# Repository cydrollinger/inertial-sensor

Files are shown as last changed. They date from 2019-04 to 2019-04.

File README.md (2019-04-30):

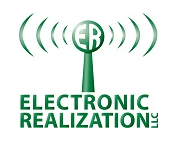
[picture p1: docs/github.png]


>Electronic Realization L.L.C.								   
>Design: 9 axis inertial sensor with bluetooth communication		   
>Engineer: Cy Drollinger								   
>Date: 2/19												           
>Email: cy@elec-real.com
>Website: https://elec-real.com								   
>Address: 2023 Stadium Dr Suite 2B #210 Bozeman, MT 59715				   
>Phone: 406-539-8117	

**NOTE:**
 This design has been tested and functions as specified. The design is provided gratis, so, please 
 think critically while utilizing and or redesigning. Open electronic circuitry can be dangerous due 
 to easily shorting circuits which can generate immediate and intense heat resulting in fire. Conversation is
 welcome to improve this design and repository, but, be advised ER is a professional design house and
 monetary compensation is required for additional work toward this design enabling your success.			   
	 
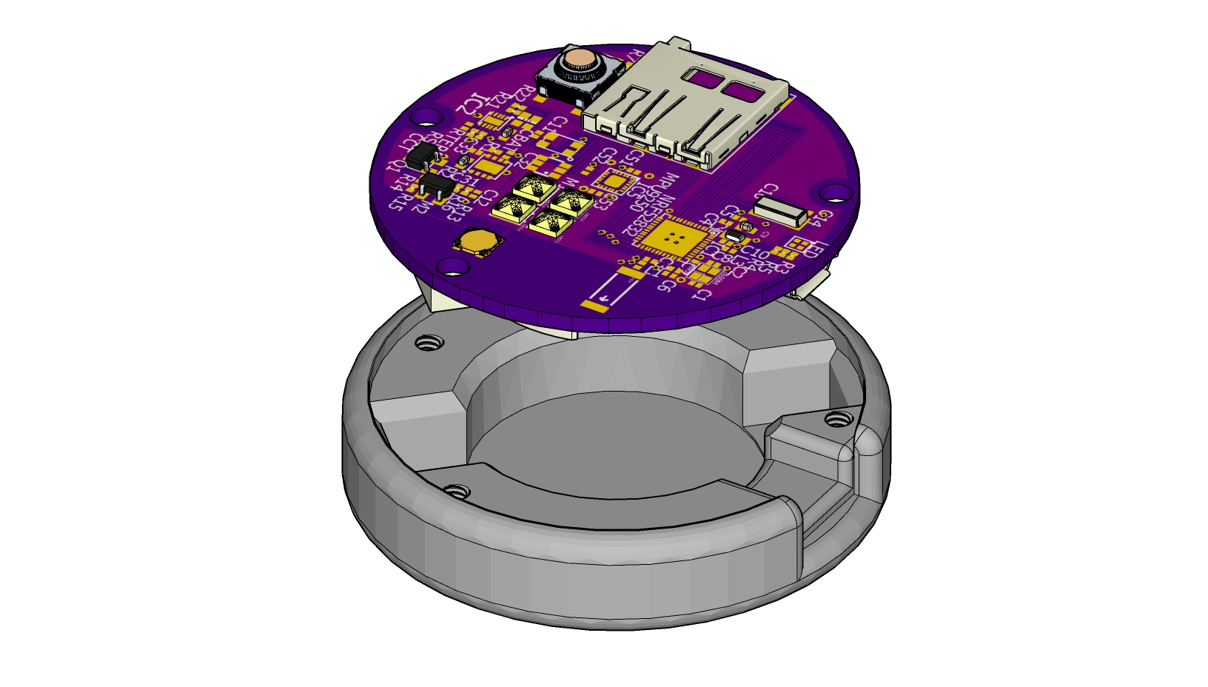
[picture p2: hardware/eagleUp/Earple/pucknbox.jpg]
Inertial Sensor


**PURPOSE:**
This electronic system is capable of sampling inertial data from the mpu9250 at 1 kHz and storing to 
a uSD card for GB storage, fatfs. The design files were created with Eagle Cadsoft v7.7 as a 
two layer board. Free Eagle version would be capable of viewing, and editing these files for redesign. 

>**File Arcitecture with a terse description**

* FOLDERS:
	* docs		: datasheets charging IC and battery holder
	* hardware	: eagle cadsoft(v7.7) hardware design files 	
		* eagleup		: 3D files 
		* library		: eagle part files 
		* manufacturing	: files required to produce the design
			* bom	: files created to order the parts
					* batteryCharger.txt	: 
					* batteryv1.1.csv	: digikey order
					* hundredUnits.txt	
			* gerber	: files generated to manufacture the board
			* 
	* firmware
	* software

	* readme.md	: this file

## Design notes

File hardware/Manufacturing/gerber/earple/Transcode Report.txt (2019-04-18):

   ---- Transcoding 'C:\Users\Cy\Documents\eagle\gerber\ERpuck\earple\toppaste.gtp' ----   Mon Feb 18 14:16:38 2019

D10   --> D100
D11   --> D101
D12   --> D102
D13   --> D103
D14   --> D104
D15   --> D105
D16   --> D106
D17   --> D107
D18   --> D108
D19   --> D109
D20   --> D110
-----------------------------------------------------------------

   ---- Transcoding 'C:\Users\Cy\Documents\eagle\gerber\ERpuck\earple\topstop.GTS' ----   Mon Feb 18 14:16:38 2019

D10   --> D111
D11   --> D112
D12   --> D113
D13   --> D114
D14   --> D115
D15   --> D116
D16   --> D117
D17   --> D118
D18   --> D119
D19   --> D120
D20   --> D121
D21   --> D122
D22   --> D123
D23   --> D124
D24   --> D125
D25   --> D126
D26   --> D127
D27   --> D128
D28   --> D129
D29   --> D130
D30   --> D131
D31   --> D132
D32   --> D133
D33   --> D134
D34   --> D135
D35   --> D136
D36   --> D137
-----------------------------------------------------------------

   ---- Transcoding 'C:\Users\Cy\Documents\eagle\gerber\ERpuck\earple\top.GTL' ----   Mon Feb 18 14:16:38 2019

D10   --> D138
D11   --> D139
D12   --> D140
D13   --> D141
D14   --> D142
D15   --> D143
D16   --> D144
D17   --> D145
D18   --> D146
D19   --> D147
D20   --> D148
D37   --> D149
D38   --> D150
D39   --> D151
D40   --> D152
D41   --> D153
D42   --> D154
D43   --> D155
D44   --> D156
D45   --> D157
D46   --> D158
-----------------------------------------------------------------

   ---- Transcoding 'C:\Users\Cy\Documents\eagle\gerber\ERpuck\earple\bottom.GBL' ----   Mon Feb 18 14:16:39 2019

D10   --> D159
D11   --> D160
D12   --> D161
D15   --> D162
D16   --> D163
D17   --> D164
D18   --> D165
D19   --> D166
D20   --> D167
D21   --> D168
D22   --> D169
D23   --> D170
-----------------------------------------------------------------

   ---- Transcoding 'C:\Users\Cy\Documents\eagle\gerber\ERpuck\earple\botstop.GBS' ----   Mon Feb 18 14:16:39 2019

D10   --> D171
D11   --> D172
D12   --> D173
D13   --> D174
D16   --> D175
D17   --> D176
D18   --> D177
D19   --> D178
D20   --> D179
D21   --> D180
D22   --> D181
D23   --> D182
D24   --> D183
D25   --> D184
D26   --> D185
D27   --> D186
D28   --> D187
-----------------------------------------------------------------

   ---- Transcoding 'C:\Users\Cy\Documents\eagle\gerber\ERpuck\earple\botpaste.gbp' ----   Mon Feb 18 14:16:39 2019

D10   --> D188
D11   --> D189
D12   --> D190
-----------------------------------------------------------------

   ---- Transcoding 'C:\Users\Cy\Documents\eagle\gerber\ERpuck\earple\botsilk.GBO' ----   Mon Feb 18 14:16:39 2019

D10   --> D191
D11   --> D192
D12   --> D193
-----------------------------------------------------------------

   ---- Transcoding 'C:\Users\Cy\Documents\eagle\gerber\ERpuck\earple\outline.GKO' ----   Mon Feb 18 14:16:39 2019

D10   --> D194
D11   --> D195
-----------------------------------------------------------------

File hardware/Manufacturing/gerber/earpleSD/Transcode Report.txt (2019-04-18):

   ---- Transcoding 'C:\Users\Cy\Documents\eagle\gerber\ERpuck\earpleSD\toppaste.gtp' ----   Mon Feb 18 14:17:45 2019

D10   --> D100
D11   --> D101
D12   --> D102
D13   --> D103
D14   --> D104
D15   --> D105
D16   --> D106
D17   --> D107
D18   --> D108
D19   --> D109
D20   --> D110
-----------------------------------------------------------------

   ---- Transcoding 'C:\Users\Cy\Documents\eagle\gerber\ERpuck\earpleSD\topstop.GTS' ----   Mon Feb 18 14:17:45 2019

D10   --> D111
D11   --> D112
D12   --> D113
D13   --> D114
D14   --> D115
D15   --> D116
D16   --> D117
D17   --> D118
D18   --> D119
D19   --> D120
D20   --> D121
D21   --> D122
D22   --> D123
D23   --> D124
D24   --> D125
D25   --> D126
D26   --> D127
D27   --> D128
D28   --> D129
D29   --> D130
D30   --> D131
D31   --> D132
D32   --> D133
D33   --> D134
D34   --> D135
D35   --> D136
D36   --> D137
D37   --> D138
D38   --> D139
D39   --> D140
-----------------------------------------------------------------

   ---- Transcoding 'C:\Users\Cy\Documents\eagle\gerber\ERpuck\earpleSD\top.GTL' ----   Mon Feb 18 14:17:45 2019

D10   --> D141
D11   --> D142
D12   --> D143
D13   --> D144
D14   --> D145
D15   --> D146
D16   --> D147
D17   --> D148
D18   --> D149
D19   --> D150
D20   --> D151
D40   --> D152
D42   --> D153
D44   --> D154
D45   --> D155
D46   --> D156
D48   --> D157
-----------------------------------------------------------------

   ---- Transcoding 'C:\Users\Cy\Documents\eagle\gerber\ERpuck\earpleSD\bottom.GBL' ----   Mon Feb 18 14:17:45 2019

D10   --> D158
D11   --> D159
D12   --> D160
D15   --> D161
D16   --> D162
D17   --> D163
D18   --> D164
D19   --> D165
D20   --> D166
D21   --> D167
-----------------------------------------------------------------

   ---- Transcoding 'C:\Users\Cy\Documents\eagle\gerber\ERpuck\earpleSD\botstop.GBS' ----   Mon Feb 18 14:17:45 2019

D10   --> D168
D11   --> D169
D12   --> D170
D13   --> D171
D16   --> D172
D17   --> D173
D18   --> D174
D19   --> D175
D20   --> D176
D21   --> D177
D22   --> D178
D23   --> D179
-----------------------------------------------------------------

   ---- Transcoding 'C:\Users\Cy\Documents\eagle\gerber\ERpuck\earpleSD\botpaste.gbp' ----   Mon Feb 18 14:17:45 2019

D10   --> D180
D11   --> D181
D12   --> D182
-----------------------------------------------------------------

   ---- Transcoding 'C:\Users\Cy\Documents\eagle\gerber\ERpuck\earpleSD\botsilk.GBO' ----   Mon Feb 18 14:17:45 2019

D10   --> D183
D11   --> D184
D12   --> D185
-----------------------------------------------------------------

   ---- Transcoding 'C:\Users\Cy\Documents\eagle\gerber\ERpuck\earpleSD\outline.GKO' ----   Mon Feb 18 14:17:45 2019

D10   --> D186
D11   --> D187
-----------------------------------------------------------------

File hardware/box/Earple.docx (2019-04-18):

Specifications:

EARPLE BOARD:

Diameter: 1.8”

Holes:

1. (0.543” , 1.637) drill 3/32” #43 #42 .089 or .0935
2. (1.69” , 0.684) drill 3/32” #43 #42 .089 or .0935
3. (0.9” , 0.088”) drill 3/32” #43 #42 .089 or .0935
4. Tap for 4-40 NF or NC

Battery: (0.9 “ , .09”) 45 deg. Offset drawing included

Micro USB: ~(0.9” , 1.68”) 0 deg. Offset drawing included

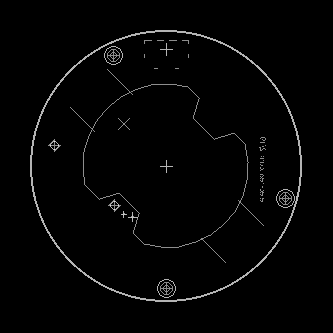
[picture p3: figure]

Electronic Realization llc 2023 Stadium Dr Ste. 2B #210 Bozeman, MT 59715 USA cell (406) 539-8117 E-mail cy@elec-real.com Web site www.elec-real.com

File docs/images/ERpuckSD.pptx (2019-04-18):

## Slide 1

12

Ay+

Gy+ ccw

9

Az+

Gz+ CCW

Ax+

3

Gx+ CCW

6

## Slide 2

Inertial Data
3 Axis acceleration
+/-16g full scale
3 Axis gyroscope
+/- 2000 deg/sec full scale
3 Axis magnetometer
+/-4800uT full scale

uUSB
In circuit serial programming
Battery charging on board Li Cell

uSD CARD
GB storage
32 bit fat file system

Light to Frequency Converter
dynamic range: 850k:1

LEDs
4 high output
1 RGB system indication

ARM Cortex –M4F 64MHz
Bluetooth v4.2/5.0

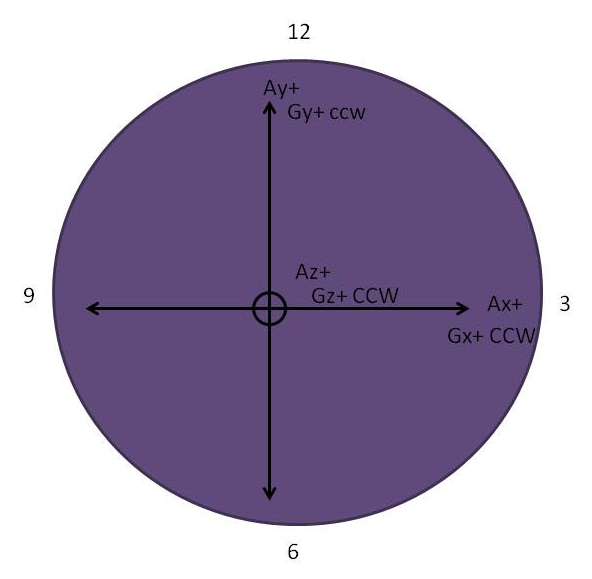
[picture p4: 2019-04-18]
docs/images/ERpuckSD.png

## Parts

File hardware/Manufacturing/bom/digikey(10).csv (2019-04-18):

Index | Quantity | Part Number | Manufacturer Part Number | Description | Customer Reference | Backorder | Unit Price | Extended Price
1 | 10 | 490-7236-1-ND | GRM0335C2AR80BA01D | CAP CER 0.8PF 100V C0G/NP0 0201 | EARPLE: C3 | 0 | 0.071 | $0.71
2 | 20 | 490-11315-1-ND | GRM0335C1H200JA01D | CAP CER 20PF 50V C0G/NP0 0201 | EARPLE: C17,C18 | 0 | 0.015 | $0.30
3 | 10 | 490-7751-1-ND | GRM0335C1H101GA01D | CAP CER 100PF 50V C0G/NP0 0201 | EARPLE: C7 | 0 | 0.02 | $0.20
4 | 10 | 490-3184-1-ND | GRM033R71E102KA01D | CAP CER 1000PF 25V X7R 0201 | EARPLE: C32 | 0 | 0.027 | $0.27
5 | 10 | 490-7194-1-ND | GRM033R61E103KA12D | CAP CER 10000PF 25V X5R 0201 | EARPLE: C51 | 0 | 0.019 | $0.19
6 | 100 | 490-5405-1-ND | GRM033R61A104ME15D | CAP CER 0.1UF 10V X5R 0201 | EARPLE: C4, C5 C8, C52, C53,, C11,CCT, | 0 | 0.0074 | $0.74
7 | 20 | 490-7229-1-ND | GRM033R60J105MEA2D | CAP CER 1UF 6.3V X5R 0201 | EARPLE: C10, C33 | 0 | 0.085 | $1.70
8 | 10 | 445-13685-1-ND | C0603X6S0G334K030BC | CAP CER 0.33UF 4V X6S 0201 | EARPLE: C12 | 0 | 0.16 | $1.60
9 | 30 | 490-5915-1-ND | GRM155R60J475ME47D | CAP CER 4.7UF 6.3V X5R 0402 | EARPLE: C31, C9, CBAT | 0 | 0.109 | $3.27
10 | 20 | 490-3144-1-ND | GRM0335C1E120JA01D | CAP CER 12PF 25V C0G/NP0 0201 | EARPLE: C1, C2 | 0 | 0.015 | $0.30
11 | 10 | SER3800CT-ND | FA-128 32.0000MF20X-K3 | CRYSTAL 32.0000MHZ 10PF SMD | EARPLE: X1 | 0 | 0.495 | $4.95
12 | 10 | XC1658CT-ND | ECS-.327-12.5-39-TR | CRYSTAL 32.7680KHZ 12.5PF SMD | EARPLE: X2 | 0 | 0.88 | $8.80
13 | 10 | H125274CT-ND | ZX62R-B-5P(30) | CONN RCPT USB2.0 MICRO B SMD R/A | EARPLE: USB | 0 | 0.965 | $9.65
14 | 10 | 490-5560-1-ND | LQP03TN3N9C02D | FIXED IND 3.9NH 400MA 300 MOHM | EARPLE: L1 | 0 | 0.044 | $0.44
15 | 10 | 490-4025-1-ND | LQM18FN100M00D | FIXED IND 10UH 50MA 900 MOHM SMD | EARPLE: L2 | 0 | 0.134 | $1.34
16 | 10 | 490-6713-1-ND | LQP03TN15NH02D | FIXED IND 15NH 250MA 700 MOHM | EARPLE: L3 | 0 | 0.047 | $0.47
17 | 25 | 160-1446-1-ND | LTST-C191KGKT | LED GREEN CLEAR SMD | EARPLE: LED1, LED2 | 0 | 0.16 | $4.00
18 | 10 | 67-2125-1-ND | SML-LX0404SIUPGUSB | LED RGB CLEAR SMD | EARPLE: LED | 0 | 1.047 | $10.47
19 | 40 | XHGAWT-00-0000-00000HXE1CT-ND | XHGAWT-00-0000-00000HXE1 | LED XLAMP COOL WHITE 6500K 2SMD | EARPLE: LED11, 12,13,14 | 0 | 0.326 | $13.04
20 | 10 | 1490-1052-1-ND | NRF52832-QFAA-R | IC RF TXRX+MCU BLUETOOTH 48VFQFN | EARPLE: IC1 | 0 | 5.119 | $51.19
21 | 10 | 863-1512-1-ND | AAT3693IDH-AA-T1 | 1.6A LINEAR LI-ION CHGR 10TDFN | EARPLE: IC2 | 0 | 0.959 | $9.59
22 | 10 | MCP1727-3302E/MF-ND | MCP1727-3302E/MF | IC REG LINEAR 3.3V 1.5A 8DFN | EARPLE: IC3 | 0 | 0.84 | $8.40
23 | 10 | W25N01GVZEIGCT-ND | W25N01GVZEIG TR | IC FLASH 1G SPI 104MHZ 8WSON | EARPLE: IC6 | 0 | 2.942 | $29.42
24 | 100 | 311-100MCT-ND | RC0201FR-07100RL | RES SMD 100 OHM 1% 1/20W 0201 | EARPLE: R1, R3, R4, R5 | 0 | 0.0171 | $1.71
25 | 20 | YAG2274CT-ND | RC0201FR-071K5L | RES SMD 1.5K OHM 1% 1/20W 0201 | EARPLE: R21, R22 | 0 | 0.042 | $0.84
26 | 100 | 311-10.0KMCT-ND | RC0201FR-0710KL | RES SMD 10K OHM 1% 1/20W 0201 | EARPLE: R6, R14, R15, R16 | 0 | 0.0171 | $1.71
27 | 10 | 311-100KMCT-ND | RC0201FR-07100KL | RES SMD 100K OHM 1% 1/20W 0201 | EARPLE: RSET | 0 | 0.042 | $0.42
28 | 10 | 311-100KMCT-ND | RC0201FR-07100KL | RES SMD 100K OHM 1% 1/20W 0201 | EARPLE: R2 | 0 | 0.042 | $0.42
29 | 10 | 311-1MMCT-ND | RC0201FR-071ML | RES SMD 1M OHM 1% 1/20W 0201 | EARPLE: R13 | 0 | 0.042 | $0.42
30 | 10 | YAG2435CT-ND | RC0201FR-0716K5L | RES SMD 16.5K OHM 1% 1/20W 0201 | EARPLE: RTERM | 0 | 0.042 | $0.42
31 | 10 | 490-4644-1-ND | NCP03XH103J05RL | THERMISTOR NTC 10KOHM 3380K 0201 | EARPLE: RTHERM | 0 | 0.18 | $1.80
32 | 10 | EG5715CT-ND | TL3312NF160Q | ULTRA-MINIATURE 3.7MM X 3.7MM LO | EARPLE SW1 | 0 | 0.385 | $3.85
33 | 10 | 401-1932-ND | MDSLFS | SWITCH PUSH SPST-NO 0.1A 100V | EARPLE: SW2 | 0 | 2.257 | $22.57
34 | 10 | 1727-4926-1-ND | BSH201,215 | MOSFET P-CH 60V 300MA SOT-23 | EARPLE: M2 | 0 | 0.438 | $4.38
35 | 10 | 2SC2412KT146RCT-ND | 2SC2412KT146R | TRANS NPN 50V 0.15A SOT-346 | EARPLE: Q1 | 0 | 0.196 | $1.96
36 | 10 | ANT-2.45-CHPCT-ND | ANT-2.45-CHP-T | RF ANT 2.4GHZ CHIP SOLDER SMD | EARPLE: ANTEENA | 0 | 1.41 | $14.10
37 | 10 | BU2450SM-JJ-GCT-ND | BU2450SM-JJ-GTR | BATTERY HOLDER COIN 24.5MM SMD | EARPLE BATTERY | 0 | 1.423 | $14.23
38 | 25 | RPC1579-ND | NSP-4-3-01 | MACHINE SCREW PAN PHILLIPS 4-40 |  | 0 | 0.0452 | $1.13
39 | 10 | YAG2302CT-ND | RT0402BRD0715KL | RES SMD 15K OHM 0.1% 1/16W 0402 | 4057C002: R61 | 0 | 0.304 | $3.04
40 | 100 | 311-15JRCT-ND | RC0402JR-0715RL | RES SMD 15 OHM 5% 1/16W 0402 | 4057C: R61A | 0 | 0.0057 | $0.57
41 | 10 | 732-3819-1-ND | 6.93E+11 | CONN MICRO SD CARD PUSH-PUSH R/A | EARPLE: uSDCard |  | 2.856 | $28.56
 |  |  |  |  |  |  | total | $263.17

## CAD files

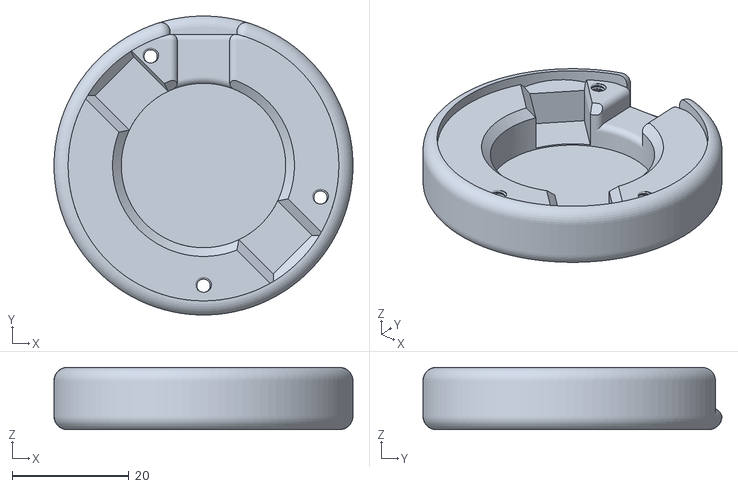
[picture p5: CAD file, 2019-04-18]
hardware/box/ERpuck Final Files/ERpuck_final.stl.stl
51.3 x 51.3 x 10.7

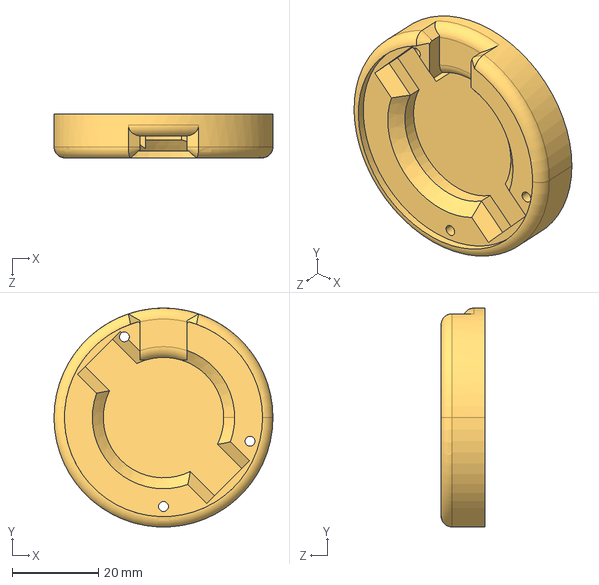
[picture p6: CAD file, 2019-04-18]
hardware/box/EarpleBox.STEP
50.8 x 50.8 x 10.2 mm

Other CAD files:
hardware/box/Assem1.SLDASM
hardware/box/earple_brd.SLDPRT
hardware/box/ERpuck Final Files/alliesBox.SLDPRT
hardware/box/ERpuck Final Files/ERpuck_final.stp
hardware/box/ERpuck Final Files/ERpuck_final.obj.obj
hardware/box/ERpuck Final Files/ERpuck_final.skp
hardware/box/EarpleBox.SLDPRT

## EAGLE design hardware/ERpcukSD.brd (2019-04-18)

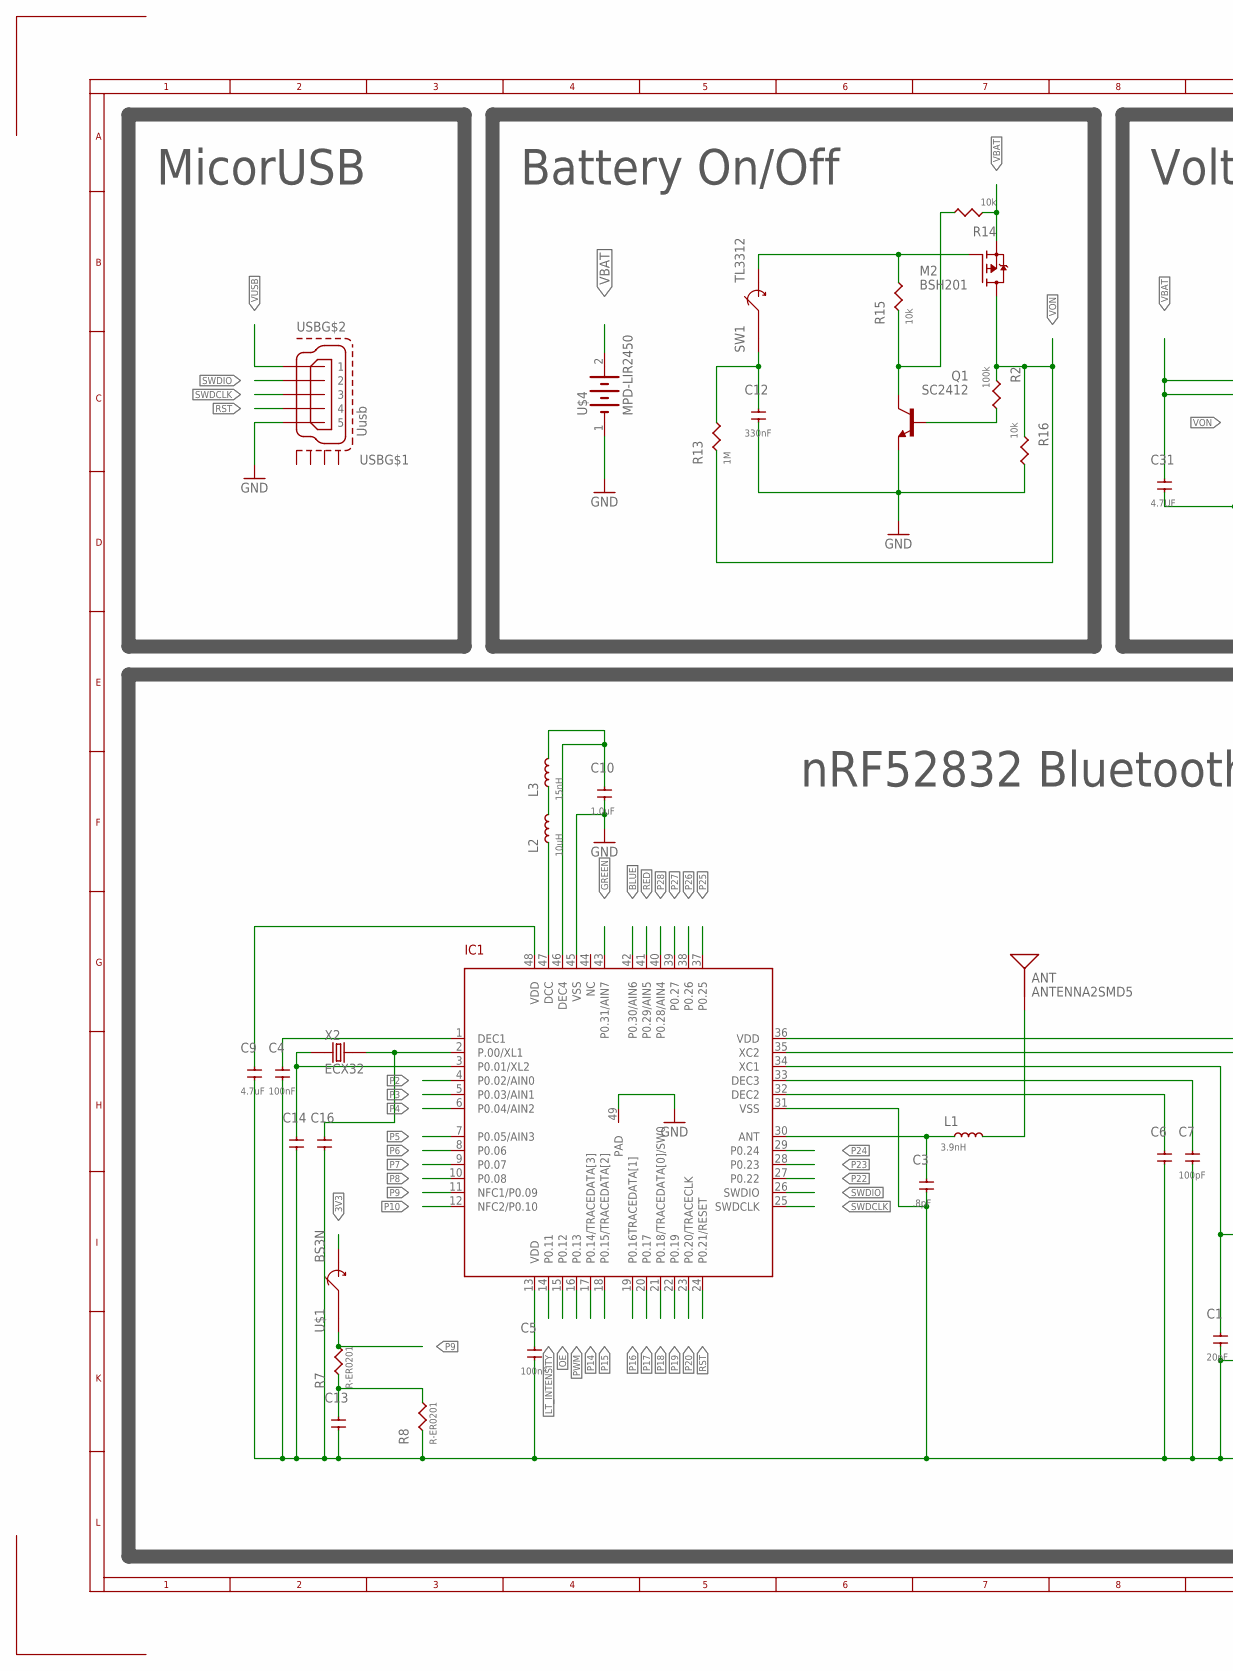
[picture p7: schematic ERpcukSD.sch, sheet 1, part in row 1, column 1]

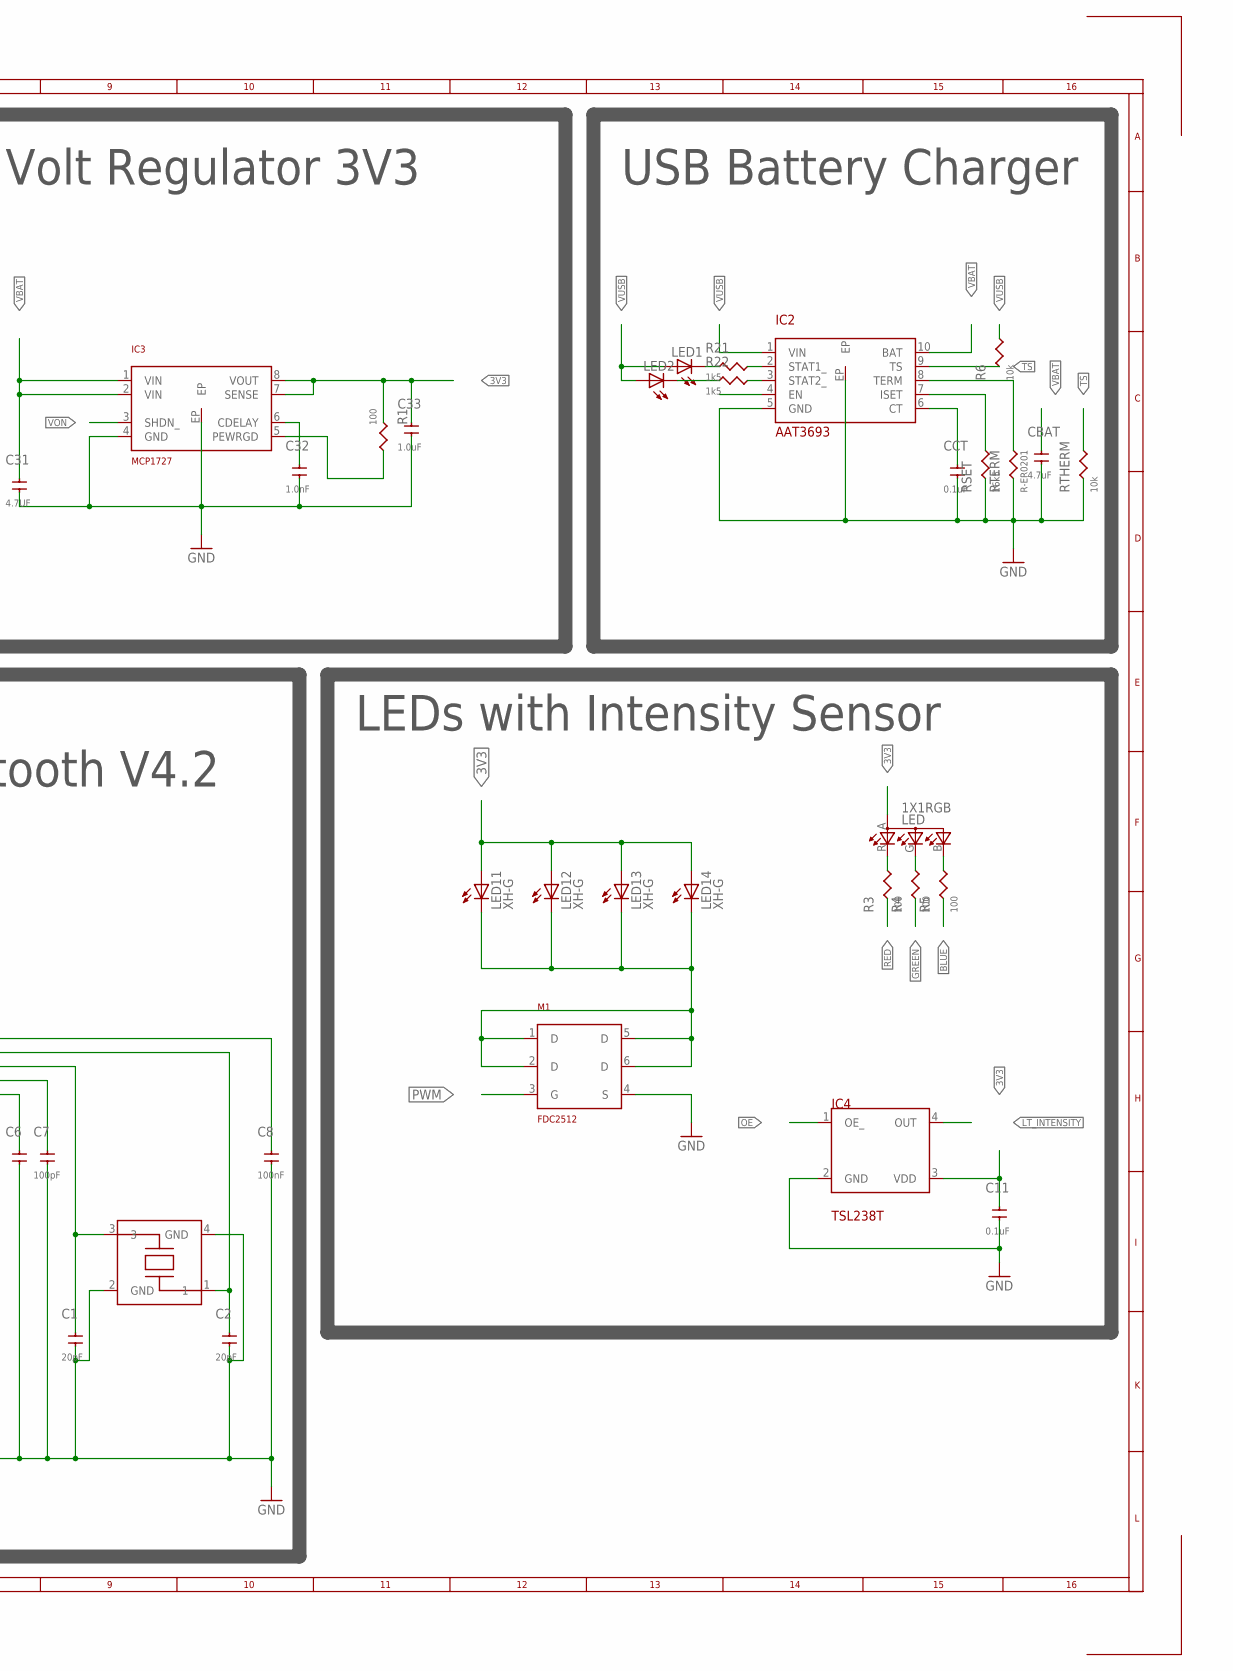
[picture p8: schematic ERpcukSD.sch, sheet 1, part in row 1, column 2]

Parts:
ANT: ANTENNA2SMD5; ANTENNA-CHIP5
C1, C2: 20pF; C0201
C3: .8pF; C0201
C4, C5, C8: 100nF; C0201
C6, C13, C14, C16: C-ER201; C0201
C7: 100pF; C0201
C9: 4.7uF; C0402
C10, C33: 1.0uF; C0201
C11: 0.1uF; C0201
C12: 330nF; C0201
C31: 4.7UF; C0402
C32: 1.0nF; C0201
CBAT: 4.7uF; C0402
CCT: 0.1uF; C0201
IC1: NRF52832; QFN48
IC2: AAT3693
IC3: MCP1727; DFN8-3X3
IC4: TSL238T; T4
L1: 3.9nH; C0201
L2: 10uH; R0603
L3: 15nH; C0201
LED: 1X1RGB; 1X1
LED1, LED2: LEDCHIP-LED0603; CHIP-LED0603
LED11, LED12, LED13, LED14: XH-G
M1: FDC2512; SSOT6
M2: BSH201; SOT23
Q1: SC2412; SC59-BEC
R1, R3, R4, R5: 100; R0201
R2: 100k; R0201
R6, R14, R15, R16: 10k; R0201
R7, R8: R-ER0201; R0201
R13: 1M; R0201
R21, R22: 1k5; R0201
RSET: 16k5; R0201
RTERM: R-ER0201; R0201
RTHERM: 10k; R0201
SW1: TL3312; DIGIKEY EG4620CT-ND
U$1: BS3N
U$4: MPD-LIR2450; LIR2450
USB: Uusb; ZX62R-B-5P
X1: FA-128
X2: ECX32; ECX39

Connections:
3V3: C5.2, C8.2, C9.2, C11.2, C33.2, IC1.13 (VDD), IC1.36 (VDD), IC1.48 (VDD), IC3.7 (SENSE), IC3.8 (VOUT), IC4.3 (VDD), LED.A (A2), LED11.2 (A), LED12.2 (A), LED13.2 (A), LED14.2 (A), R1.1, U$1.2; also elsewhere on the board
BLUE: IC1.42 (P0.30/AIN6), R5.1
GND: C1.1, C2.1, C3.1, C4.1, C5.1, C6.1, C7.1, C8.1, C9.1, C10.1, C11.1, C12.1, C13.1, C14.1, C16.1, C31.1, C32.1, C33.1, CBAT.1, CCT.1, IC1.31 (VSS), IC1.45 (VSS), IC1.49 (PAD), IC2.5 (GND), IC2.EP, IC3.4 (GND), IC3.EP, IC4.2 (GND), M1.4 (S), Q1.E, R8.1, R16.2, RSET.1, RTERM.1, RTHERM.1, U$4.1 (-), USB.1 (5), X1.2 (GND), X1.4 (GND); also elsewhere on the board
GREEN: IC1.43 (P0.31/AIN7), R4.1
LT_INTENSITY: IC1.14 (P0.11), IC4.4 (OUT)
unnamed: LED11.1 (C), LED12.1 (C), LED13.1 (C), LED14.1 (C), M1.1 (D), M1.2 (D), M1.5 (D), M1.6 (D)
unnamed: Q1.B, R2.2
unnamed: C3.2, IC1.30 (ANT), L1.1
unnamed: C6.2, IC1.32 (DEC2)
unnamed: ANT.FEED, L1.2
unnamed: C7.2, IC1.33 (DEC3)
unnamed: C1.2, IC1.34 (XC1), X1.3
unnamed: C2.2, IC1.35 (XC2), X1.1
unnamed: Q1.C, R14.2, R15.1
unnamed: IC1.47 (DCC), L2.1
unnamed: L2.2, L3.1
unnamed: C10.2, IC1.46 (DEC4), L3.2
unnamed: C12.2, R13.2, SW1.1
unnamed: LED.B (CGREEN), R5.2
unnamed: CCT.2, IC2.6 (CT)
unnamed: IC2.7 (ISET), RSET.2
unnamed: IC2.8 (TERM), RTERM.2
unnamed: IC2.3 (STAT2_), R22.2
unnamed: IC2.2 (STAT1_), R21.2
unnamed: LED1.C, R21.1
unnamed: LED2.C, R22.1
unnamed: LED.G (CBLUE), R4.2
unnamed: IC3.5 (PEWRGD), R1.2
unnamed: LED.R (CRED), R3.2
unnamed: C32.2, IC3.6 (CDELAY)
unnamed: M2.1 (G), R15.2, SW1.3 (2)
unnamed: C16.2, IC1.2 (P.00/XL1), X2.P$2 (2)
unnamed: C14.2, IC1.3 (P0.01/XL2), X2.P$1 (1)
unnamed: C4.2, IC1.1 (DEC1)
unnamed: C13.2, R7.1, R8.2
OE: IC1.15 (P0.12), IC4.1 (OE_)
P2: IC1.4 (P0.02/AIN0); also elsewhere on the board
P3: IC1.5 (P0.03/AIN1); also elsewhere on the board
P4: IC1.6 (P0.04/AIN2); also elsewhere on the board
P5: IC1.7 (P0.05/AIN3); also elsewhere on the board
P6: IC1.8 (P0.06); also elsewhere on the board
P7: IC1.9 (P0.07); also elsewhere on the board
P8: IC1.10 (P0.08); also elsewhere on the board
P9: IC1.11 (NFC1/P0.09), R7.2, U$1.1
P10: IC1.12 (NFC2/P0.10); also elsewhere on the board
P14: IC1.17 (P0.14/TRACEDATA[3]); also elsewhere on the board
P15: IC1.18 (P0.15/TRACEDATA[2]); also elsewhere on the board
P16: IC1.19 (P0.16TRACEDATA[1]); also elsewhere on the board
P17: IC1.20 (P0.17); also elsewhere on the board
P18: IC1.21 (P0.18/TRACEDATA[0]/SW0); also elsewhere on the board
P19: IC1.22 (P0.19); also elsewhere on the board
P20: IC1.23 (P0.20/TRACECLK); also elsewhere on the board
P22: IC1.27 (P0.22); also elsewhere on the board
P23: IC1.28 (P0.23)
P24: IC1.29 (P0.24)
P25: IC1.37 (P0.25)
P26: IC1.38 (P0.26)
P27: IC1.39 (P0.27)
P28: IC1.40 (P0.28/AIN4)
PWM: IC1.16 (P0.13), M1.3 (G)
RED: IC1.41 (P0.29/AIN5), R3.1
RST: IC1.24 (P0.21/RESET), USB.2 (4)
SWDCLK: IC1.25 (SWDCLK), USB.3
SWDIO: IC1.26 (SWDIO), USB.4 (2)
TS: IC2.9 (TS), R6.1, RTHERM.2
VBAT: C31.2, CBAT.2, IC2.10 (BAT), IC3.1 (VIN), IC3.2 (VIN), M2.2 (S), R14.1, U$4.2 (+)
VON: IC3.3 (SHDN_), M2.3 (D), R2.1, R13.1, R16.1
VUSB: IC2.1 (VIN), IC2.4 (EN), LED1.A, LED2.A, R6.2, USB.5 (1)

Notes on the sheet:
nRF52832 Bluetooth V4.2
MicorUSB
Battery On/Off
Volt Regulator 3V3
USB Battery Charger
LEDs with Intensity Sensor

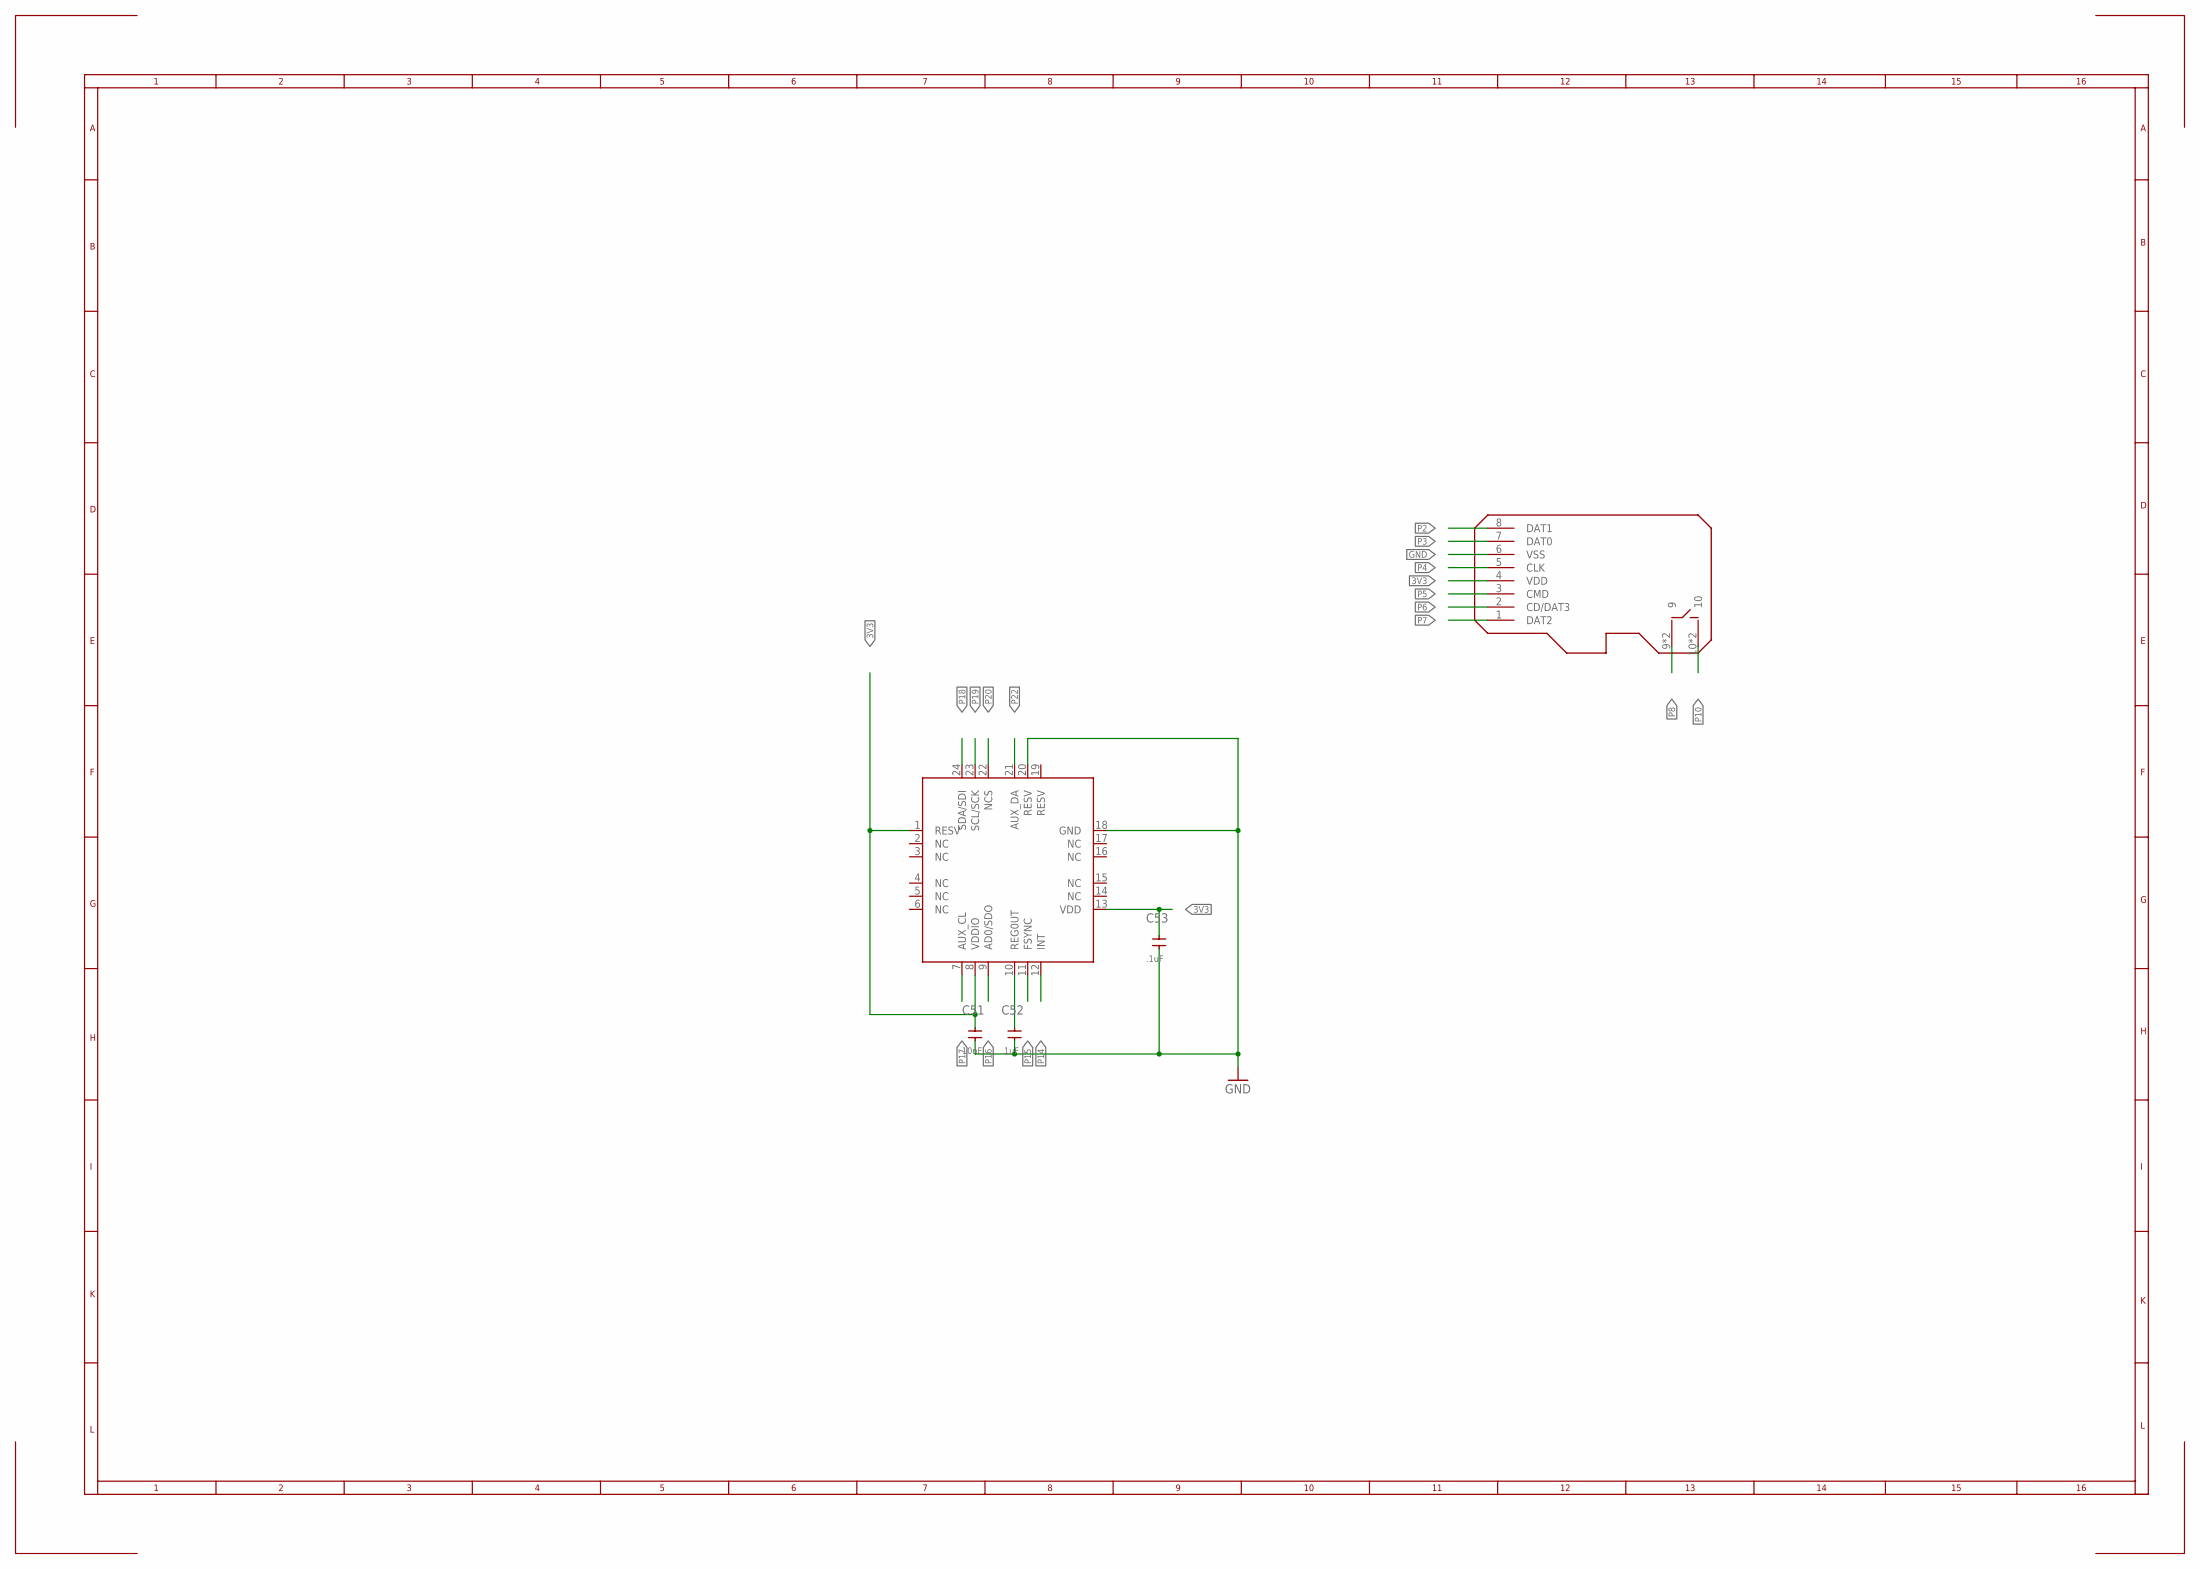
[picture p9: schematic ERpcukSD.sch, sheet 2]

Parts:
C51: 10nF; C0201
C52, C53: .1uF; C0201
IC5: MPU9250; 3X3_24_QFN_CORRECTED
U$2: MICROSD

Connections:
3V3: C51.2, C53.2, IC5.1 (RESV), IC5.8 (VDDIO), IC5.13 (VDD), U$2.4 (VDD); also elsewhere on the board
GND: C51.1, C52.1, C53.1, IC5.18 (GND), IC5.20 (RESV), U$2.6 (VSS); also elsewhere on the board
unnamed: C52.2, IC5.10 (REG0UT)
P2: U$2.8 (DAT1); also elsewhere on the board
P3: U$2.7 (DAT0); also elsewhere on the board
P4: U$2.5 (CLK); also elsewhere on the board
P5: U$2.3 (CMD); also elsewhere on the board
P6: U$2.2 (CD/DAT3); also elsewhere on the board
P7: U$2.1 (DAT2); also elsewhere on the board
P8: U$2.9, U$2.9@1 (9); also elsewhere on the board
P10: U$2.10, U$2.10@1 (10); also elsewhere on the board
P14: IC5.12 (INT); also elsewhere on the board
P15: IC5.11 (FSYNC); also elsewhere on the board
P16: IC5.9 (AD0/SDO); also elsewhere on the board
P17: IC5.7 (AUX_CL); also elsewhere on the board
P18: IC5.24 (SDA/SDI); also elsewhere on the board
P19: IC5.23 (SCL/SCK); also elsewhere on the board
P20: IC5.22 (NCS); also elsewhere on the board
P22: IC5.21 (AUX_DA); also elsewhere on the board

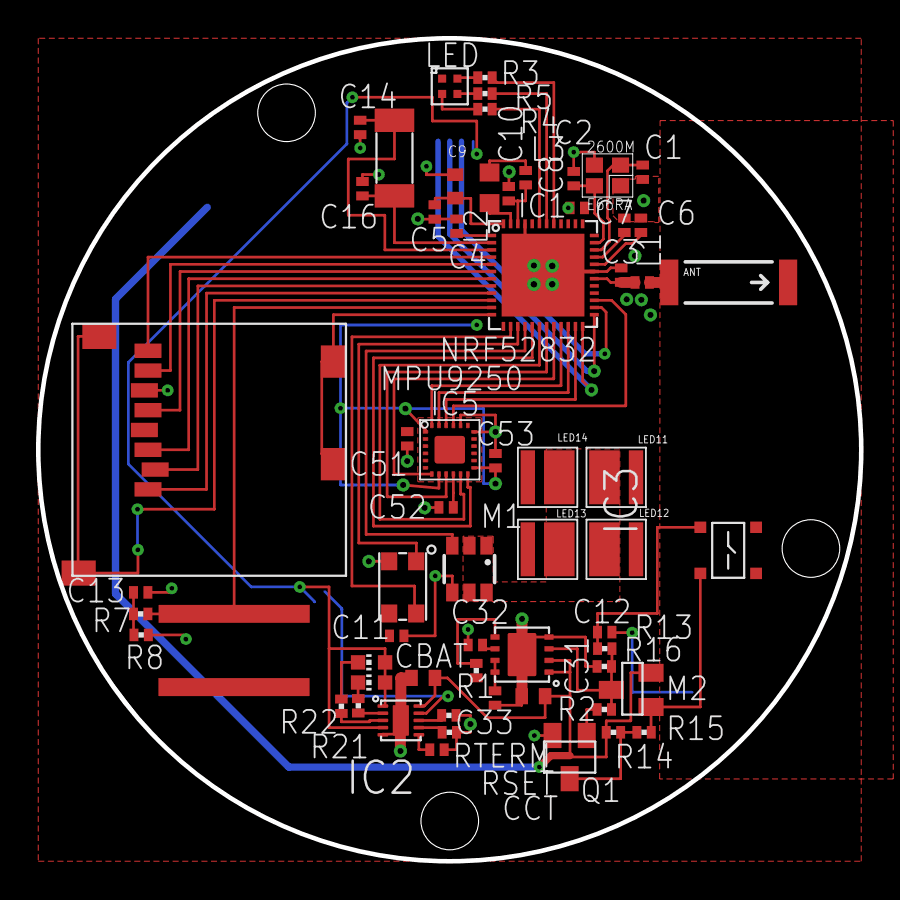
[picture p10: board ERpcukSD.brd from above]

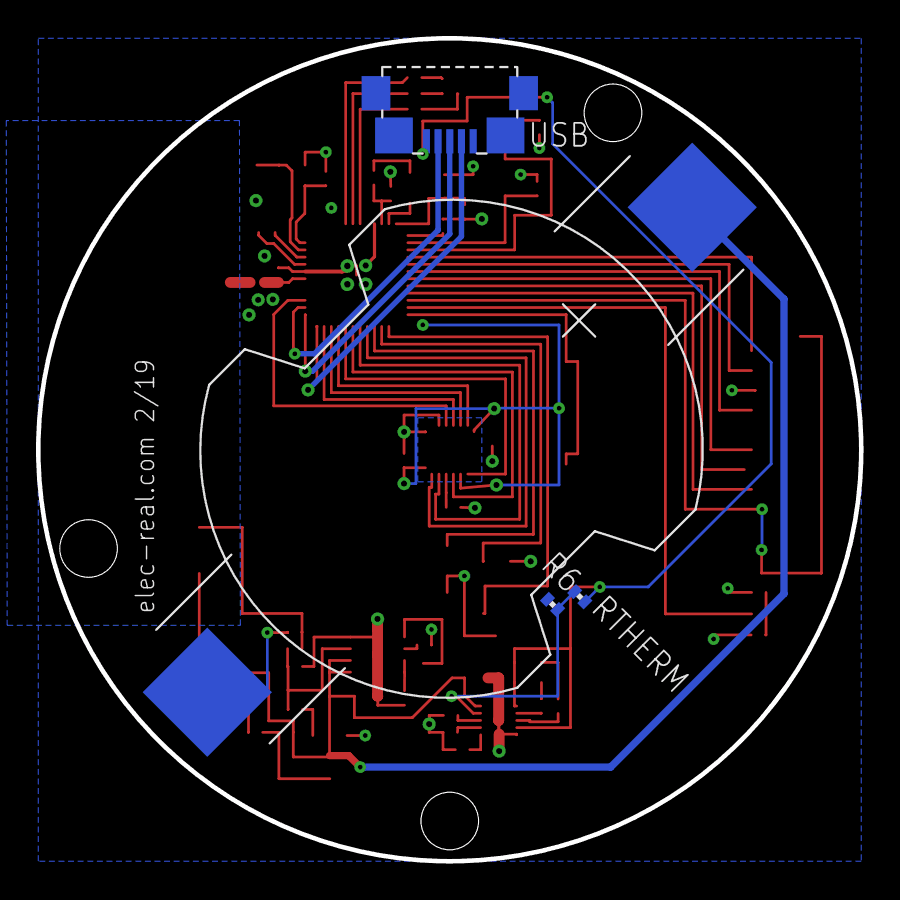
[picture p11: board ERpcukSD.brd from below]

Board: 2 copper layers, 45.7 x 45.7 mm, 66 parts (4 on the bottom side), 63 nets.

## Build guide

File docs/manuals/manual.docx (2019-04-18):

1. Turn the Puck on, press flat little yellow button. Tiny Led at the edge of the board flashes blue.
  a. A hard press with a tactile sensation, click
2. Open: BST Device Gateway application (blue MT silhouette) on the/a smart hand held Android device. [This can be acquired by any android device at google play store.]
3. Here we can cancel, and scan on the touch screen and we can use the back button of the Android device.
  a. Cancel and scan detects active Puck (ER Puck Logger 2)
  b. If you have two on you can turn one off and cycle cancel and scan
  c. Select by pressing the ER Puck Logger 2 label
    i. This takes you into the active data recording screen
      1. Press the back arrow of the android device to see and acquire Puck/s
4. Active data screen:
  a. Select sample rate
  b. Input a file preamble to identify data
  c. Press Record when ready
  d. Press stop when finished
  e. repeat
5. Acquiring data off the hand held smart device, the device acts as a USB drive and only needs to be plugged into a PC through USB. Navigate to the folder DCIM. Where the file are located. If you do not see the files and they have not been removed power cycle the ZTE phone and re-plug into the PC.

ZTE pattern access:

Nine dots: start at the upper left, swipe diagonally down to the lower right and vertically up the right hand column like a check mark.

Electronic Realization llc 2023 Stadium Dr Ste. 2B #210 Bozeman, MT 59715 USA cell (406) 539-8117 E-mail cy@elec-real.com Web site www.elec-real.com

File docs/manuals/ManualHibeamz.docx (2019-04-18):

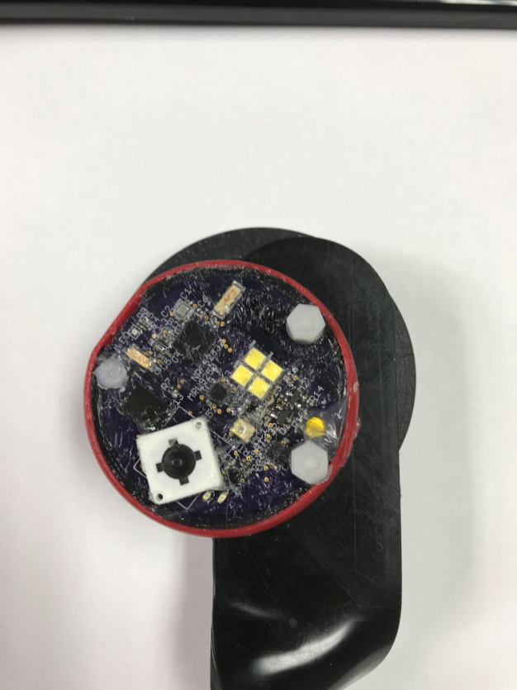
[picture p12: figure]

Power on/off

Press firm the little yellow button above the bottom attaching nut you should feel and here a click.

An LED will lit near the micro USB port and blink blue

HighBeamz

Once powered bush the big black button with the white housing, press again to turn off HighBeamz.

Electronic Realization llc 2023 Stadium Dr Ste. 2B #210 Bozeman, MT 59715 USA cell (406) 539-8117 E-mail cy@elec-real.com Web site www.elec-real.com

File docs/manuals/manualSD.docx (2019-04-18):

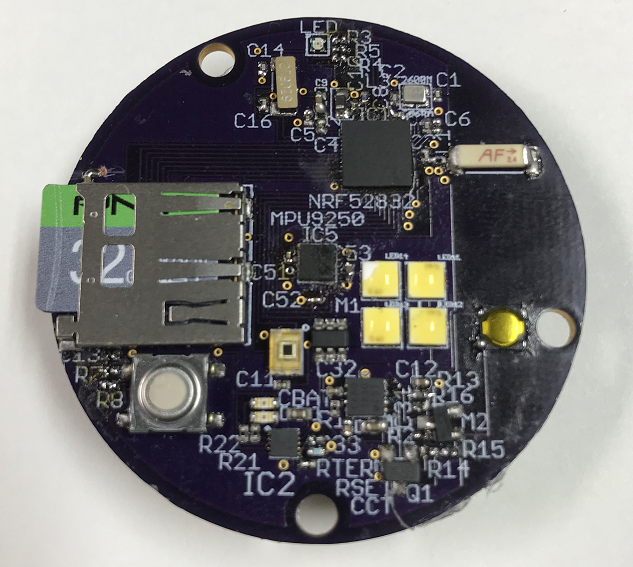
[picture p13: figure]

1. LED at the top of the board (12 o’clock), solid green LED powered on, solid blue LED recording, LED off the device is either asleep or it is powered off.
  a. The device can go from asleep to recording with the touch of the button, located under the micro SD card, (9 o’clock).
2. Power button is the flat yellow button to the right edge of the board, (approximately 3 o’clock)
  a. Hard press with a slight audible and tactile click, will lit the LED solid green.
  b. The device will create/open a file, NORDIC.TXT, on the micro SD card and write the text: SD CARD EXAMPLE. The phrase will indicate how many power cycles the device has undergone before reading the data off the micro SD card.
  c. The device either creates or appends a file, if the device has been power cycled an existing file will be appended. So if DATA0.CSV already exists data will be appended at the end of the file and therefore DATA0.csv could be several data sets with different events and meaning.
3. Recording data sets on the device requires the device to be powered on and the button under the micro SD card (3 o’clock) pressed solid blue LED indication. Sample rate is 1 kHz.

Electronic Realization llc 2023 Stadium Dr Ste. 2B #210 Bozeman, MT 59715 USA cell (406) 539-8117 E-mail cy@elec-real.com Web site www.elec-real.com
